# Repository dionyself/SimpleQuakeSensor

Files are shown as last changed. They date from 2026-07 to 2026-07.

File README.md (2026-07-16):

# Simple Quake Sensor 
SimpleQuake Sensor is an Earthquake Analyzer. (Work in Progress)  
Useful to capture and analyze Natural EM wave emitions and Earthquake EM emitions.  
The circuit works as an EM ear and broadband receiver  

### Primary EM waves 0 - 40 Hz  
- Ultra Low Frequency: f < 3 Hz  
- Extremely Low Frequency: 3 Hz < f < 3 kHz  
- Very Low Frequency: 3 kHz < f < 30 kHz  

### Secundary Emitions  30 kHz - 5.8 gHz  
- High Frequency: 3 MHz < f < 30 MHz  
- Very High Frequency: 30 MHz < f < 300 MHz    

### Real PCB View (from Kicad 3D viewer)
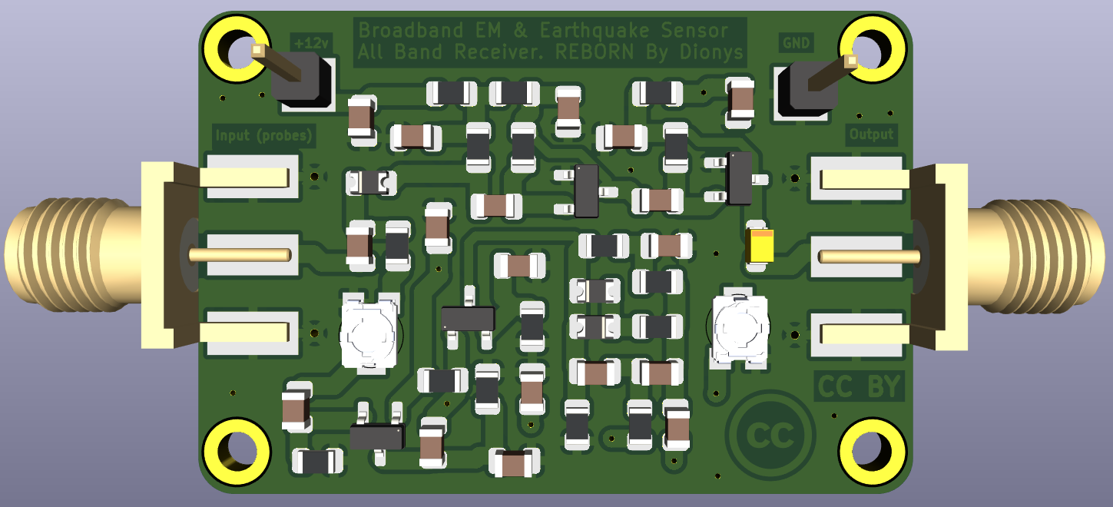
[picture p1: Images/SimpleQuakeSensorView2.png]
Real World View.


## How to use it?

1 - Assembly the device  (gerber files provided <here>)  
2 - Connect your device to your audio card / pc using this <> cable  
3 - Connect your device's input to ground using 2 probes and a good coaxial cable <example>  
4 - Take audio samples as you like: `parec raw_sample.raw --file-format=raw` ( Linux command )  
              or    
5 - Use your favorite Audio analizer to listen and view the live data `jaaa -A -d hw:1`  

### My Results

I have included images, screenshoots and audio files captured during relevant events:  

a) 0 - 1.5 kHz

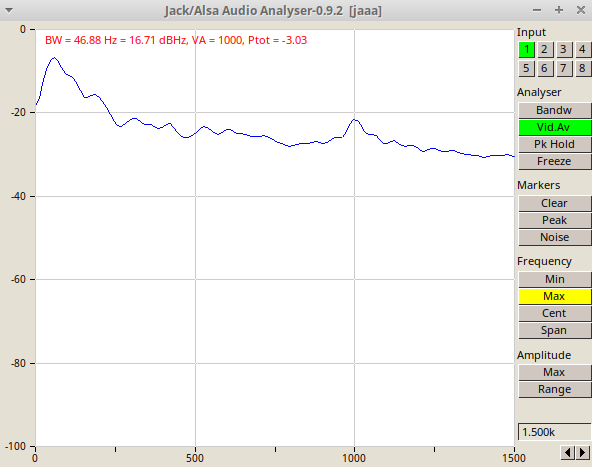
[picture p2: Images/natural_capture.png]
First Natural Capture.


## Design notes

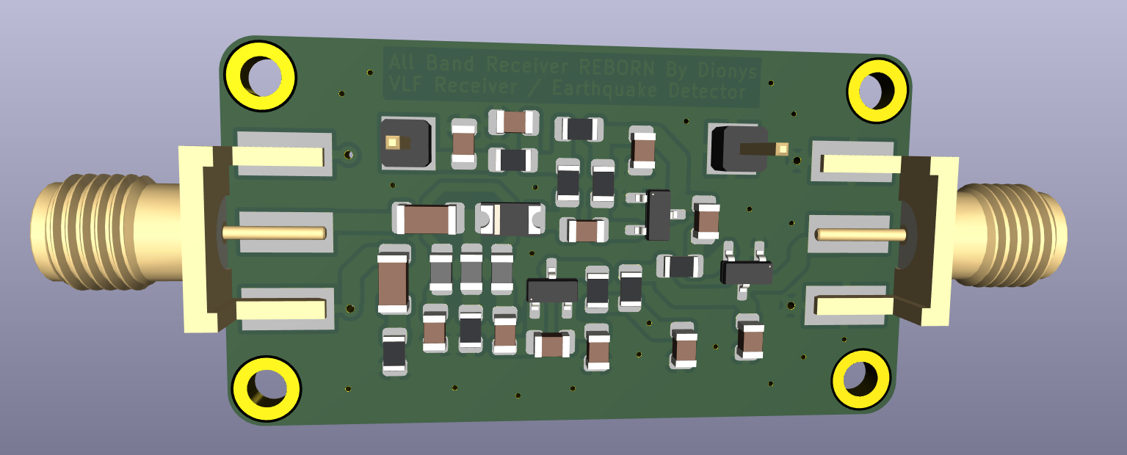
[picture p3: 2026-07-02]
Images/SimpleQuakeSensorView.png

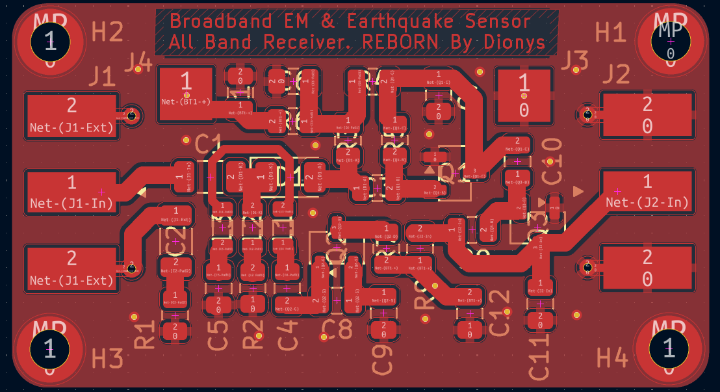
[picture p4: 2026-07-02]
Images/SimpleQuakeSensorFoot.png

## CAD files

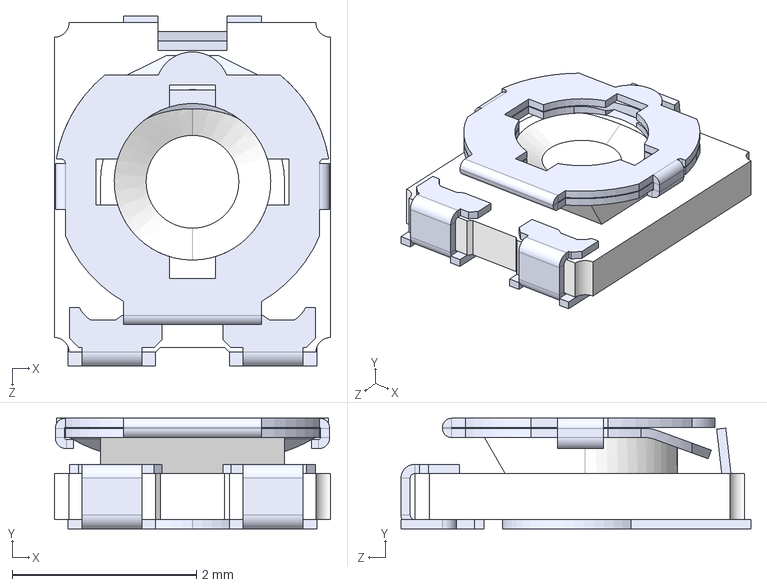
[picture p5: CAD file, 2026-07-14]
models/TC33X-2-102G.STEP
3.00 x 1.20 x 3.80 mm

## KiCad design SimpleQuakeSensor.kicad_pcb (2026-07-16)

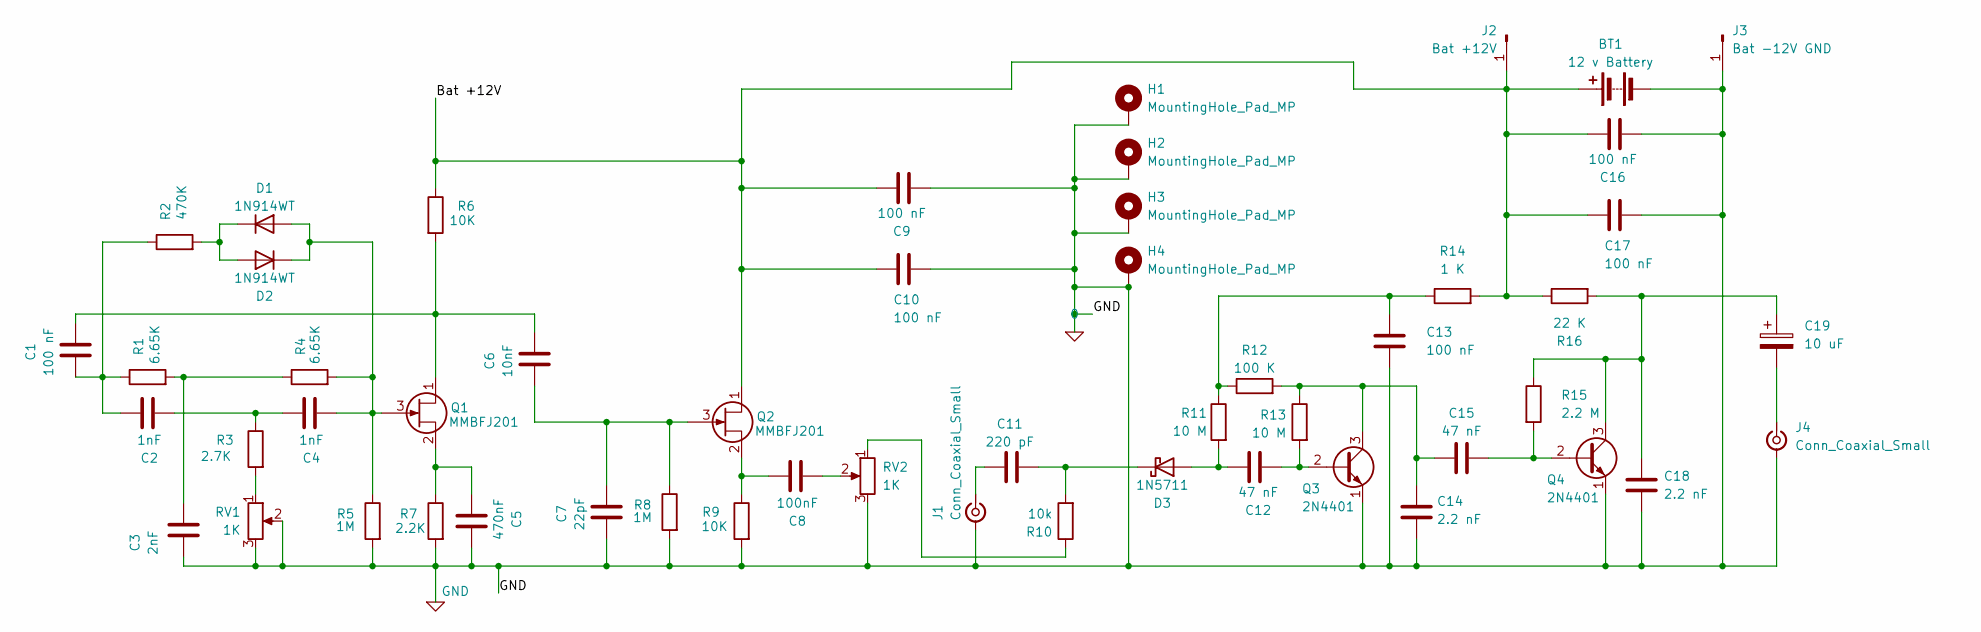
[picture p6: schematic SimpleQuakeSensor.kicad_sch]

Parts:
BT1: 12 v Battery
C1, C9, C10, C13, C16, C17: 100 nF; C_0805_2012Metric
C2, C4: 1nF; C_0805_2012Metric
C3: 2nF; C_0805_2012Metric
C5: 470nF; C_0805_2012Metric
C6: 10nF; C_0805_2012Metric
C7: 22pF; C_0805_2012Metric
C8: 100nF; C_0805_2012Metric
C11: 220 pF; C_0805_2012Metric
C12, C15: 47 nF; C_0805_2012Metric
C14, C18: 2.2 nF; C_0805_2012Metric
C19: 10 uF; CP_EIA-2012-15_AVX-P
D1, D2: 1N914WT; D_0805_2012Metric
D3: 1N5711; D_0805_2012Metric
H1, H2, H3, H4: MountingHole_Pad_MP; MountingHole_2.2mm_M2_DIN965_Pad_TopBottom
J1, J4: Conn_Coaxial_Small; SMA_Molex_73251-1153_EdgeMount_Horizontal
J2: Bat +12V; PinHeader_1x01_P2.54mm_Vertical_2_FMD
J3: Bat -12V GND; PinHeader_1x01_P2.54mm_Vertical_2_FMD
Q1, Q2: MMBFJ201; SOT-23-3
Q3, Q4: 2N4401; SOT-23-3
R1, R4: 6.65K; R_0805_2012Metric
R2: 470K; R_0805_2012Metric
R3: 2.7K; R_0805_2012Metric
R5, R8: 1M; R_0805_2012Metric
R6, R9: 10K; R_0805_2012Metric
R7: 2.2K; R_0805_2012Metric
R10: 10k; R_0805_2012Metric
R11, R13: 10 M; R_0805_2012Metric
R12: 100 K; R_0805_2012Metric
R14: 1 K; R_0805_2012Metric
R15: 2.2 M; R_0805_2012Metric
R16: 22 K; R_0805_2012Metric
RV1, RV2: 1K; Potentiometer_Bourns_TC33X_Vertical

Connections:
0: BT1.2 (-), C3.1, C5.1, C7.2, C9.2, C10.1, C13.2, C14.2, C16.2, C17.1, C18.2, H1.MP (MP_MP), H2.MP (MP_MP), H3.MP (MP_MP), H4.MP (MP_MP), J1.2 (Ext), J3.1 (Pin_1_1), J4.2 (Ext), Q3.1 (E), Q4.1 (E), R5.2, R7.2, R8.2, R9.2, RV1.2, RV1.3, RV2.3
/Bat +12V: BT1.1 (+), C9.1, C10.2, C16.1, C17.2, J2.1 (Pin_1_1), Q2.1 (D), R6.1, R14.2, R16.1
unnamed: C1.2, C2.1, R1.1, R2.1
unnamed: C2.2, C4.1, R3.1
unnamed: C3.2, R1.2, R4.1
unnamed: C8.2, RV2.2
unnamed: C13.1, R11.1, R12.1, R14.1
unnamed: C4.2, D1.2 (A), D2.1 (K), Q1.3 (G), R4.2, R5.1
unnamed: D1.1 (K), D2.2 (A), R2.2
unnamed: C12.1, D3.2 (A), R11.2
unnamed: C11.2, D3.1 (K), R10.2
unnamed: C11.1, J1.1 (In)
unnamed: C19.2, J4.1 (In)
unnamed: C1.1, C6.1, Q1.1 (D), R6.2
unnamed: C5.2, Q1.2 (S), R7.1
unnamed: C6.2, C7.1, Q2.3 (G), R8.1
unnamed: C8.1, Q2.2 (S), R9.1
unnamed: C12.2, Q3.2 (B), R13.2
unnamed: C14.1, C15.2, Q3.3 (C), R12.2, R13.1
unnamed: C15.1, Q4.2 (B), R15.2
unnamed: C18.1, C19.1, Q4.3 (C), R15.1, R16.2
unnamed: R3.2, RV1.1
unnamed: R10.1, RV2.1

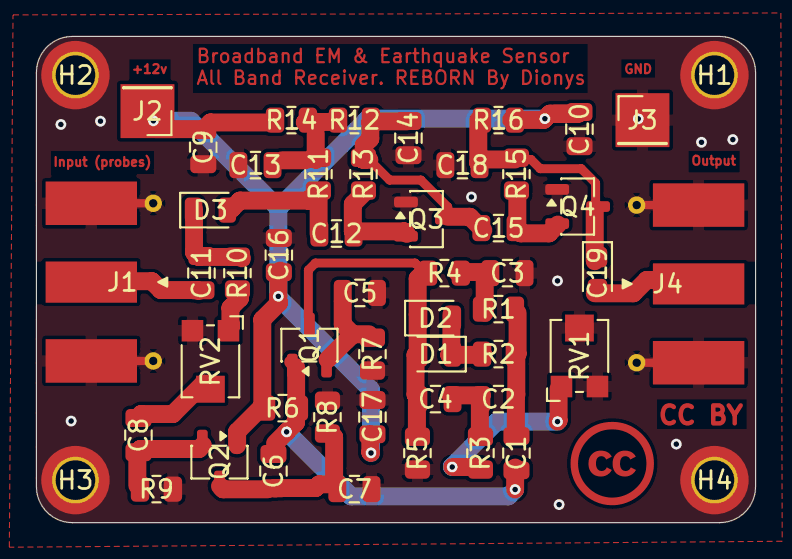
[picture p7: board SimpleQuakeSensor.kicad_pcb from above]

Board: 2 copper layers, 39.9 x 27.0 mm, 52 parts (0 on the bottom side), 23 nets.

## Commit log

2026-07-02 Initial files
    [SimpleQuakeSensor.kicad_pcb, SimpleQuakeSensor.kicad_sch]
2026-07-08 Add blocking capacitor
    [SimpleQuakeSensor.kicad_pcb, SimpleQuakeSensor.kicad_sch]
2026-07-11 Better impedance matching
    [SimpleQuakeSensor.kicad_pcb, SimpleQuakeSensor.kicad_sch]
2026-07-14 Updating osc, potentiometers, models, licence logo
    [SimpleQuakeSensor.kicad_pcb, SimpleQuakeSensor.kicad_sch, TC33X-2-102G.STEP]
2026-07-15 PCB update
    [SimpleQuakeSensor.kicad_pcb, SimpleQuakeSensor.kicad_sch]
2026-07-16 Updating PCB grid
    [SimpleQuakeSensor.kicad_pcb]

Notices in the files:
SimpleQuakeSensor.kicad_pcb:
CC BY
